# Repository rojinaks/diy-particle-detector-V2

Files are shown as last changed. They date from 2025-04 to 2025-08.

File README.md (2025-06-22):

# 🎛️ DIY Particle Detector v2.3

**Ein kompakter Teilchendetektor für Bildungs- und Outreach-Zwecke**, inspiriert vom DIY-particle-detector von Oliver Keller, weiterentwickelt am Physikalischen Institut der Universität Bonn.

---

### Dieses Repository enthält die Hardware- und Softwarebasis für einen DIY-Teilchendetektors

## ✨ Features

- SMD-basiertes PCB-Design  
- Python-Oszilloskop zur Signalvisualisierung 
- Dokumentierte Tests und Messergebnisse (Raumladungszone, Signal/noise Analyse)

---

## 📦 Inhalt

- `/hardware` → KiCad-Designs und Schaltpläne  
- `/codes` → Python-Auslesetool mit GUI, weitere messungen (Dioden Messung (Raumladungszone), Opamp vergleiche, Signal/noise Analyse)
- `/archives` → Weitere KiCad-Designs für vorherige Versionen  
- `/spice` → LTspice simulationen für verschiedene opamps

---

## Python Oszilloskop

```bash
  git clone https://github.com/rojinaks/diy-particle-detector-V2.git
  cd diy-particle-detector-V2/codes/auslese
  python oscilloscope.py

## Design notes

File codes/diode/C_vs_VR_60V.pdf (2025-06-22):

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

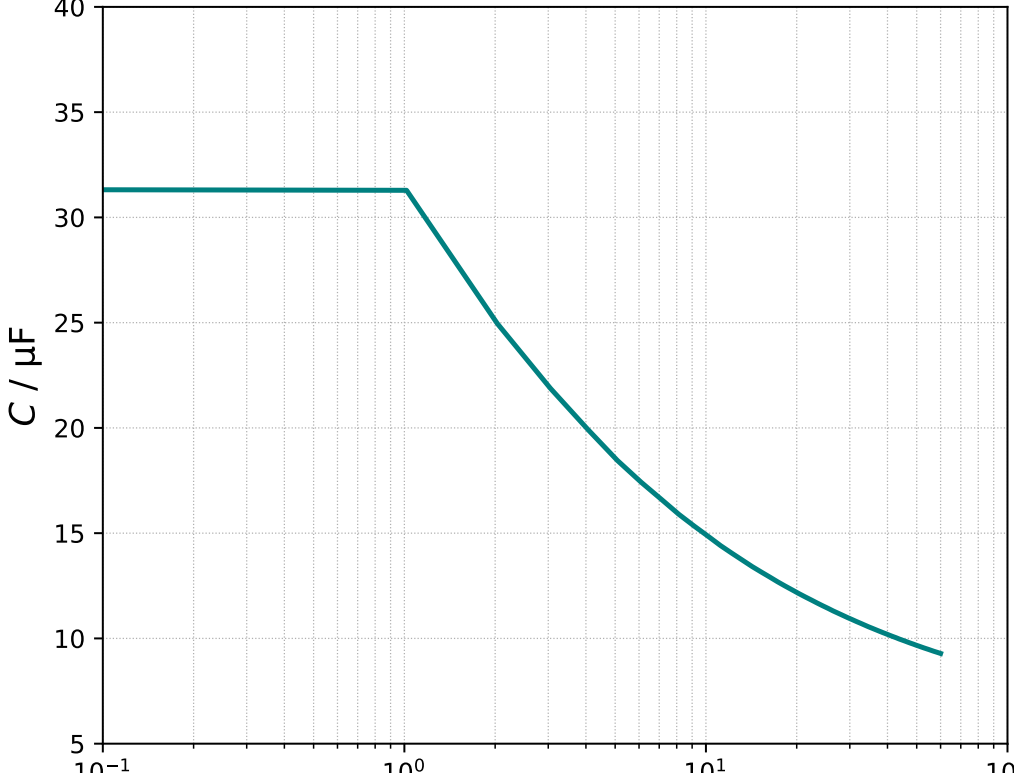
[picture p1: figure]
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

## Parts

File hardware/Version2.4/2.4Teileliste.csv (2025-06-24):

Reference | Qty | Value | DNP | Exclude from BOM | Exclude from Board | Footprint | Datasheet
C1,C2,C5 | 3 | 10p |  |  |  | Capacitor_SMD:C_0805_2012Metric | ~
C3,C4,C6,C7,C9 | 5 | 100n |  |  |  | Capacitor_SMD:C_0805_2012Metric | ~
C8 | 1 | 47mikro |  |  |  | footprints:PCAP_EEHZ_D_PAN | ~
D1,D2,D3,D4 | 4 | BPW34-SMD |  |  |  | footprints:LED_VBPW34S_VIS | https://dammedia.osram.info/media/resource/hires/osram-dam-5488319/BPW%2034%20S_EN.pdf
J1 | 1 | Conn_01x02 |  |  |  | footprints:CUI_SJ2-35813B-SMT-TR | ~
R1 | 1 | 4.7k |  |  |  | Resistor_SMD:R_0805_2012Metric | ~
R2 | 1 | 15k |  |  |  | Resistor_SMD:R_0805_2012Metric | ~
R3 | 1 | 4.7Mega |  |  |  | Resistor_SMD:R_0805_2012Metric | ~
R4 | 1 | 1k |  |  |  | Resistor_SMD:R_0805_2012Metric | ~
R5 | 1 | 100k |  |  |  | Resistor_SMD:R_0805_2012Metric | ~
R6,R7 | 2 | 10k |  |  |  | Resistor_SMD:R_0805_2012Metric | ~
R9 | 1 | 1.6k |  |  |  | Resistor_SMD:R_0805_2012Metric | ~
SW2 | 1 | SW_SPST |  |  |  | footprints:SWITCH_102AGRLC | ~
TP1 | 1 | - |  |  |  | Connector_PinHeader_2.54mm:PinHeader_1x01_P2.54mm_Vertical | ~
TP2 | 1 | + |  |  |  | Connector_PinHeader_2.54mm:PinHeader_1x01_P2.54mm_Vertical | ~
TP3,TP5 | 2 | TestPoint |  |  |  | Connector_PinHeader_2.54mm:PinHeader_1x01_P2.54mm_Vertical | ~
U1 | 1 | AD8092ARZ-REEL7 |  |  |  | footprints:R_8_ADI | AD8092ARZ-REEL7

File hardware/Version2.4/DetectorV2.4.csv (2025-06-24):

Id | Designator | Footprint | Quantity | Designation | Supplier and ref
1 | TP3,TP5 | PinHeader_1x01_P2.54mm_Vertical | 2 | TestPoint
2 | TP2 | PinHeader_1x01_P2.54mm_Vertical | 1 | +
3 | J1 | CUI_SJ2-35813B-SMT-TR | 1 | Conn_01x02
4 | R6,R7 | R_0805_2012Metric | 2 | 10k
5 | C1,C5,C2 | C_0805_2012Metric | 3 | 10p
6 | C9 | PCAP_EEHZ_D_PAN | 1 | 47mikro
7 | SW2 | SWITCH_102AGRLC | 1 | SW_SPST
8 | D3,D4,D1,D2 | LED_VBPW34S_VIS | 4 | BPW34-SMD
9 | C8,C3,C7,C4,C6 | C_0805_2012Metric | 5 | 100n
10 | TP1 | PinHeader_1x01_P2.54mm_Vertical | 1 | -
11 | R5 | R_0805_2012Metric | 1 | 100k
12 | U1 | R_8_ADI | 1 | AD8092ARZ-REEL7
13 | R8 | R_0805_2012Metric | 1 | 2.2k
14 | R1 | R_0805_2012Metric | 1 | 4.7k
15 | R3 | R_0805_2012Metric | 1 | 15Mega
16 | R2 | R_0805_2012Metric | 1 | 15k
17 | R4 | R_0805_2012Metric | 1 | 1k

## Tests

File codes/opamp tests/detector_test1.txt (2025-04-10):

time	V(output)
0.000000000000000e+00	4.457908e-14
4.999999980020986e-12	1.077057e-11
9.999999960041972e-12	1.287759e-11
7.999999968033578e-11	-4.102484e-11
3.199999987213431e-10	5.803861e-12
5.048191999967347e-05	-1.297262e-07
1.016819199996747e-04	-1.232862e-07
1.528819199996759e-04	-7.572640e-08
2.040819199996772e-04	-5.882045e-08
2.552819199996724e-04	-3.688593e-08
3.064819199996459e-04	-3.444984e-08
3.576819199996194e-04	-6.742303e-08
4.088819199995929e-04	-3.954036e-08
4.600819199995664e-04	-2.296448e-08
4.999997000000000e-04	-1.382142e-08
5.000000000000000e-04	-1.382315e-08
5.000000300000000e-04	-3.184307e-08
5.000000900000000e-04	-6.434022e-08
5.000001800000001e-04	-9.239285e-08
5.000003000000000e-04	-1.027593e-07
5.000003120000000e-04	-9.669981e-08
5.000003360000000e-04	-8.123373e-08
5.000003840000000e-04	-5.311550e-08
5.000004799999999e-04	-2.460597e-08
5.000006719999998e-04	-8.022090e-09
5.000018239999994e-04	5.711786e-08
5.000033599999988e-04	-1.537475e-07
5.000064319999976e-04	-3.442640e-06
5.000125759999953e-04	-2.187164e-05
5.000233673569872e-04	-7.606066e-05
5.000449500709712e-04	-2.053976e-04
5.001881154989391e-04	-1.040404e-03
5.003381154989392e-04	-1.818958e-03
5.004881154989393e-04	-2.507623e-03
5.006381154989394e-04	-3.099794e-03
5.007881154989395e-04	-3.638366e-03
5.009381154989395e-04	-4.123341e-03
5.010881154989396e-04	-4.554718e-03
5.012381154989397e-04	-4.932497e-03
5.013881154989398e-04	-5.256678e-03
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

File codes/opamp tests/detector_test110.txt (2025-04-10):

time	V(output)
0.000000000000000e+00	4.457908e-14
4.999997000000000e-04	-1.149799e-08
5.000000000000000e-04	-1.150331e-08
5.000000300000000e-04	-2.974804e-08
5.000000900000000e-04	-6.287148e-08
5.000001800000001e-04	-9.184528e-08
5.000003000000000e-04	-1.030562e-07
5.000003120000000e-04	-9.693772e-08
5.000003360000000e-04	-8.130880e-08
5.000003840000000e-04	-5.269109e-08
5.000004799999999e-04	-2.327454e-08
5.000006719999998e-04	-5.955013e-09
5.000018239999994e-04	6.010367e-08
5.000033599999988e-04	-1.476795e-07
5.000064319999976e-04	-3.427491e-06
5.000125759999953e-04	-2.184159e-05
5.000233665898433e-04	-7.601692e-05
5.000449477695392e-04	-2.053274e-04
5.001498858748780e-04	-8.201343e-04
5.002734373667720e-04	-1.465756e-03
5.005205403505599e-04	-2.548371e-03
5.010147463181359e-04	-4.102728e-03
5.019913088181359e-04	-5.934027e-03
5.029678713181359e-04	-6.801216e-03
5.039444338181359e-04	-7.063652e-03
5.049209963181359e-04	-7.059992e-03
5.068741213181359e-04	-6.772818e-03
5.116174248895645e-04	-5.852124e-03
5.163607284609930e-04	-5.008081e-03
5.211040320324216e-04	-4.240687e-03
5.258473356038502e-04	-3.549942e-03
5.305906391752788e-04	-2.935848e-03
5.353339427467073e-04	-2.398404e-03
5.400772463181359e-04	-1.937609e-03
5.446810409609930e-04	-1.538960e-03
5.492848356038503e-04	-1.176703e-03
5.538886302467074e-04	-8.508357e-04
5.584924248895646e-04	-5.613596e-04
5.630962195324217e-04	-3.082743e-04
5.677000141752789e-04	-9.157981e-05
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

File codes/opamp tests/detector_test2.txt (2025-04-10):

time	V(output)
0.000000000000000e+00	9.900045e-16
8.176825127106248e-07	-2.700443e-06
1.635365025421250e-06	-5.966769e-06
2.453047538131874e-06	-9.798978e-06
3.270730050842499e-06	-1.419707e-05
4.088412563553124e-06	-1.916104e-05
4.906095076263748e-06	-2.469090e-05
5.723777588974371e-06	-3.078664e-05
9.351009731831518e-06	-4.238709e-05
1.297824187468867e-05	-5.249124e-05
1.660547401754581e-05	-6.109908e-05
2.023270616040296e-05	-6.821061e-05
2.385993830326011e-05	-7.382583e-05
2.748717044611726e-05	-7.794475e-05
3.111440258897439e-05	-8.056736e-05
4.143806330326012e-05	-8.432712e-05
5.176172401754585e-05	-8.591930e-05
6.208538473183157e-05	-8.534389e-05
7.240904544611731e-05	-8.260089e-05
8.273270616040303e-05	-7.769031e-05
9.305636687468875e-05	-7.061214e-05
1.033800275889745e-04	-6.136639e-05
1.255268095773091e-04	-4.460414e-05
1.476735915656437e-04	-2.966823e-05
1.698203735539783e-04	-1.655864e-05
1.919671555423129e-04	-5.275388e-06
2.141139375306476e-04	4.181536e-06
2.362607195189822e-04	1.181213e-05
2.584075015073167e-04	1.761639e-05
2.629010563200887e-04	4.727535e-05
2.638229841095085e-04	4.463470e-05
2.647449118989284e-04	4.239051e-05
2.656668396883483e-04	4.054276e-05
2.665887674777682e-04	3.909146e-05
2.675106952671881e-04	3.803660e-05
2.684326230566079e-04	3.737820e-05
2.693545508460278e-04	3.711625e-05
2.740978544174563e-04	3.581382e-05
2.788411579888849e-04	3.439125e-05
2.835844615603135e-04	3.284855e-05
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

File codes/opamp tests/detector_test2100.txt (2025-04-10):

time	V(output)
0.000000000000000e+00	4.500020e-14
1.661160391134096e-05	-4.121589e-05
3.322320782268191e-05	-7.298883e-05
4.983481173402286e-05	-9.531881e-05
6.644641564536382e-05	-1.082058e-04
8.305801955670478e-05	-1.116499e-04
9.966962346804573e-05	-1.056510e-04
1.162812273793867e-04	-9.020913e-05
1.710981948966172e-04	-6.331407e-05
2.259151624138477e-04	-4.118642e-05
2.807321299310782e-04	-2.382618e-05
3.355490974483086e-04	-1.123336e-05
3.903660649655391e-04	-3.407946e-06
4.451830324827697e-04	-3.499476e-07
5.000000000000000e-04	-2.059362e-06
5.000000300000000e-04	-2.062032e-06
5.000000900000000e-04	-2.070502e-06
5.000001800000001e-04	-2.087911e-06
5.000003000000000e-04	-2.113405e-06
5.000003120000000e-04	-2.114961e-06
5.000003360000000e-04	-2.116687e-06
5.000004799999999e-04	-2.097844e-06
5.000006719999998e-04	-2.058885e-06
5.000010559999997e-04	-2.029344e-06
5.000018239999994e-04	-2.039168e-06
5.000031574759732e-04	-2.026207e-06
5.000072979111673e-04	-2.805569e-06
5.000116793956119e-04	-6.327371e-06
5.000178842841656e-04	-1.724781e-05
5.000273975666252e-04	-4.527592e-05
5.000391748948888e-04	-9.291667e-05
5.000525291308653e-04	-1.580664e-04
5.000719727481850e-04	-2.623872e-04
5.001477850951595e-04	-6.789644e-04
5.002332670349800e-04	-1.122735e-03
5.003730729582297e-04	-1.787976e-03
5.005635627429600e-04	-2.584830e-03
5.008303668230145e-04	-3.517586e-03
5.011796253414716e-04	-4.474500e-03
5.016543045588546e-04	-5.406892e-03
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

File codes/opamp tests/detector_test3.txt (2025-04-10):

time	V(output)
0.000000000000000e+00	9.917662e-16
1.785714274861660e-10	-1.752318e-07
3.571428549723319e-10	-3.727277e-07
5.357142824584979e-10	-5.924878e-07
7.142857099446638e-10	-8.345120e-07
8.928571374308298e-10	-1.098800e-06
1.071428564916996e-09	-1.385353e-06
1.249999992403161e-09	-1.694169e-06
2.499999984806323e-09	-2.570045e-06
4.999999969612645e-09	-2.384566e-06
3.999999975690116e-08	1.674039e-06
7.146281428550594e-05	8.634554e-07
1.428856285712550e-04	2.536647e-07
2.143084428570040e-04	-1.553336e-07
2.857312571427531e-04	-3.635395e-07
3.571540714285021e-04	-3.709529e-07
4.285768857142511e-04	-1.775738e-07
4.999997000000000e-04	2.165976e-07
5.000000000000000e-04	2.157098e-07
5.000000300000000e-04	2.020554e-07
5.000000900000000e-04	1.557575e-07
5.000001800000001e-04	4.638466e-08
5.000003000000000e-04	-1.367757e-07
5.000003120000000e-04	-1.553009e-07
5.000003360000000e-04	-1.875273e-07
5.000003840000000e-04	-2.322087e-07
5.000004799999999e-04	-2.657006e-07
5.000006719999998e-04	-2.221443e-07
5.000010559999997e-04	-2.195983e-08
5.000018239999994e-04	3.275698e-07
5.000033599999988e-04	6.399246e-07
5.000064319999976e-04	-5.064086e-08
5.000125759999953e-04	-6.665186e-06
5.000248639999906e-04	-3.646352e-05
5.000494399999812e-04	-1.303520e-04
5.000922667152987e-04	-3.303421e-04
5.001341581592522e-04	-5.358063e-04
5.001849418220838e-04	-7.789372e-04
5.002865091477471e-04	-1.233778e-03
5.004896437990737e-04	-2.036656e-03
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

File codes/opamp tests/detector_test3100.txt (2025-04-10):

time	V(output)
0.000000000000000e+00	4.508028e-14
1.785714274861660e-10	-1.776339e-07
3.571428549723319e-10	-3.791228e-07
5.357142824584979e-10	-6.044669e-07
7.142857099446638e-10	-8.536660e-07
8.928571374308298e-10	-1.126720e-06
1.071428564916996e-09	-1.423629e-06
1.249999992403161e-09	-1.744394e-06
2.499999984806323e-09	-2.659528e-06
4.999999969612645e-09	-2.463301e-06
2.714285697789723e-08	-2.949711e-07
4.928571398618181e-08	1.270683e-06
7.142857099446639e-08	2.233660e-06
9.357142800275097e-08	2.593962e-06
1.157142850110355e-07	2.351588e-06
1.378571420193201e-07	1.506538e-06
1.599999990276046e-07	5.881238e-08
4.999997000000000e-04	3.424397e-08
5.000000000000000e-04	3.339565e-08
5.000000300000000e-04	1.967624e-08
5.000000900000000e-04	-2.693382e-08
5.000001800000001e-04	-1.374386e-07
5.000003000000000e-04	-3.230272e-07
5.000003120000000e-04	-3.419420e-07
5.000003360000000e-04	-3.749843e-07
5.000003840000000e-04	-4.213241e-07
5.000004799999999e-04	-4.577254e-07
5.000006719999998e-04	-4.174168e-07
5.000010559999997e-04	-2.161339e-07
5.000018239999994e-04	1.448294e-07
5.000033599999988e-04	4.729140e-07
5.000064319999976e-04	-2.384377e-07
5.000125759999953e-04	-7.039956e-06
5.000248639999906e-04	-3.749422e-05
5.000494399999812e-04	-1.335283e-04
5.000985919999624e-04	-3.666603e-04
5.001968959999249e-04	-8.386631e-04
5.003722311177947e-04	-1.598754e-03
5.007229013535343e-04	-2.828579e-03
5.014242418250135e-04	-4.585809e-03
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

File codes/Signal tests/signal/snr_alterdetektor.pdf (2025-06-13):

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

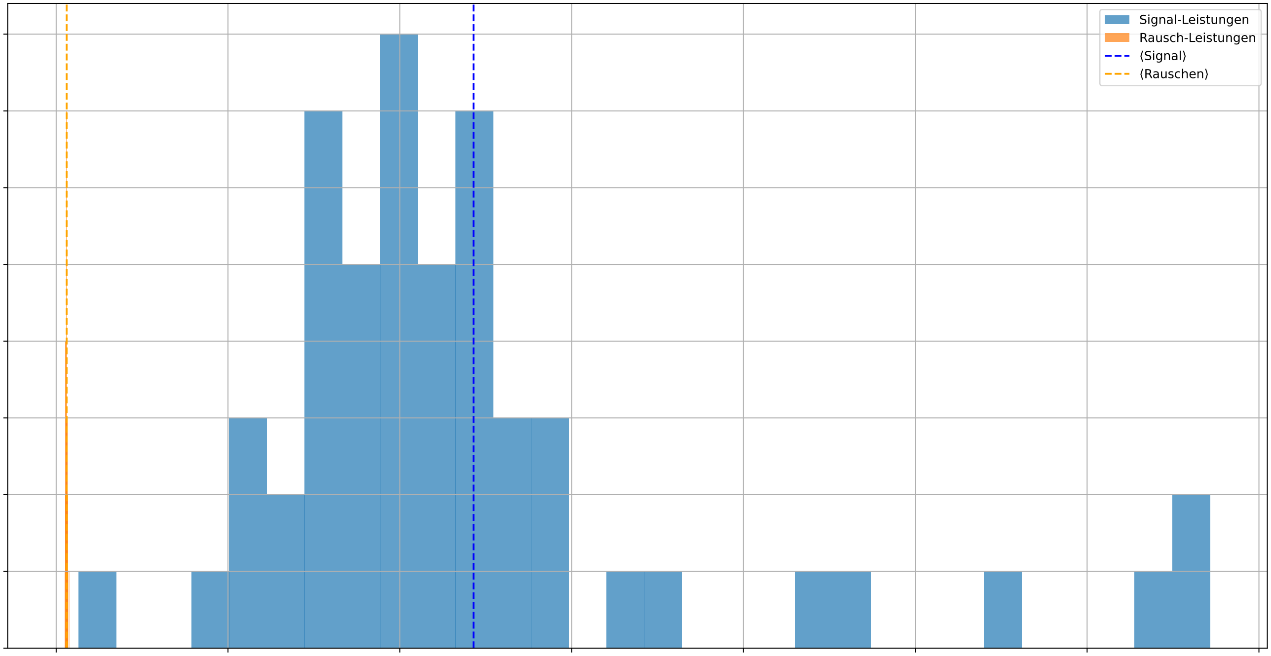
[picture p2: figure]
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

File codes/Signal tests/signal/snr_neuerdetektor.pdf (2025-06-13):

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

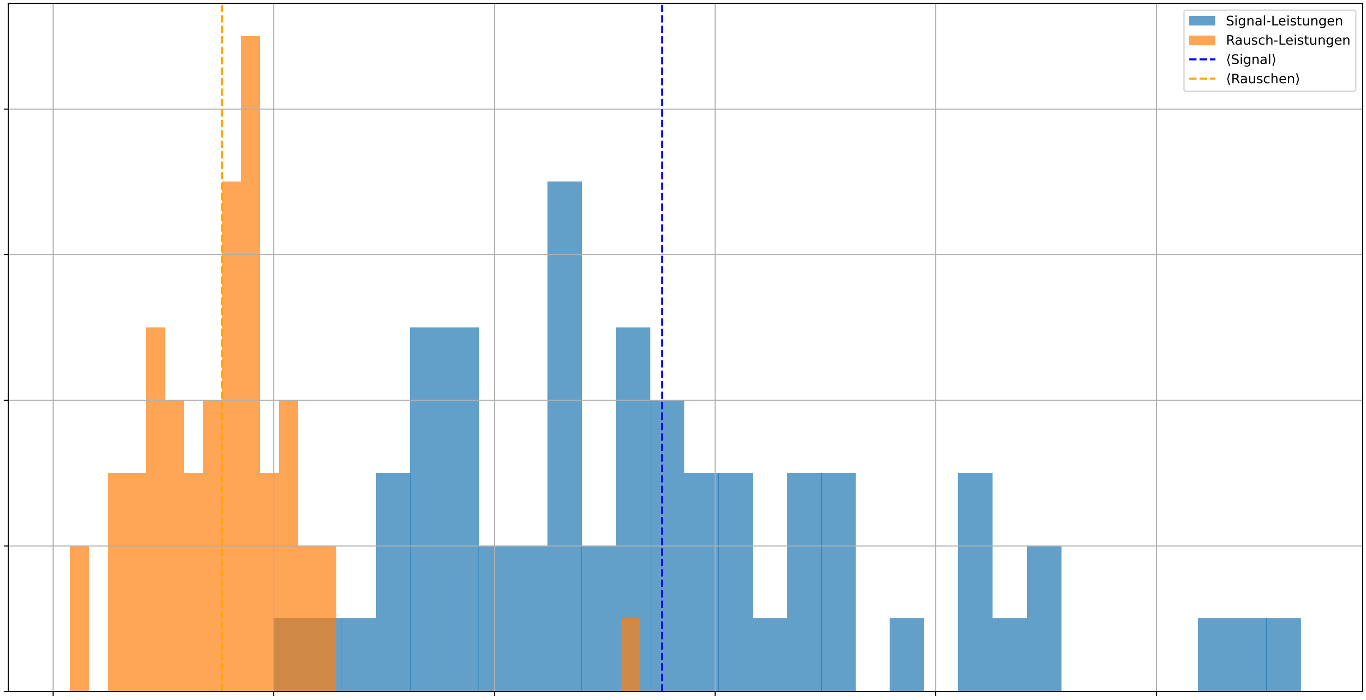
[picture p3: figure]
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

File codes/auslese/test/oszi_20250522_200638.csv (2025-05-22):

Zeit [s] | Spannung [mV]
0.0 | -7.4963317
2.269790288223468e-05 | -5.7974477
4.539580576446936e-05 | -4.0358577
6.809370864670405e-05 | 0.18808834
9.079161152893873e-05 | 6.9413195
0.0001134895144111734 | 9.741846
0.0001361874172934081 | 14.804322
0.00015888532017564277 | 19.080292
0.00018158322305787745 | 19.206087
0.00020428112594011213 | 20.819496
0.0002269790288223468 | 24.23957
0.0002496769317045815 | 20.858429
0.0002723748345868162 | 19.46584
0.00029507273746905084 | 24.058937
0.00031777064035128555 | 23.859095
0.0003404685432335202 | 23.698092
0.0003631664461157549 | 26.392279
0.0003858643489979896 | 28.499405
0.00040856225188022426 | 26.544106
0.00043126015476245897 | 30.094652
0.0004539580576446936 | 33.4248
0.0004766559605269283 | 33.244843
0.000499353863409163 | 38.714306
0.0005220517662913977 | 43.714653
0.0005447496691736324 | 42.830906
0.0005674475720558671 | 43.12498
0.0005901454749381017 | 49.081627
0.0006128433778203364 | 50.004757
0.0006355412807025711 | 51.450848
0.0006582391835848058 | 50.930145
0.0006809370864670404 | 52.732384
0.0007036349893492751 | 60.9915
0.0007263328922315098 | 62.335968
0.0007490307951137445 | 65.67565
0.0007717286979959792 | 73.397316
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

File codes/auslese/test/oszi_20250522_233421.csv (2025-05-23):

Zeit [s] | Spannung [mV]
0.0 | 37.223328
2.2681274381954655e-05 | 39.65413
4.536254876390931e-05 | 37.315243
6.804382314586397e-05 | 32.851875
9.072509752781862e-05 | 26.904228
0.00011340637190977327 | 19.945705
0.00013608764629172794 | 16.24759
0.00015876892067368258 | 16.059284
0.00018145019505563724 | 17.126307
0.0002041314694375919 | 21.47739
0.00022681274381954655 | 27.470026
0.0002494940182015012 | 34.61243
0.0002721752925834559 | 45.994343
0.0002948565669654105 | 60.976265
0.00031753784134736516 | 77.77131
0.00034021911572931985 | 98.77025
0.0003629003901112745 | 124.62876
0.0003855816644932291 | 148.63481
0.0004082629388751838 | 169.50392
0.00043094421325713846 | 189.0923
0.0004536254876390931 | 203.6952
0.0004763067620210478 | 211.5432
0.0004989880364030024 | 213.91193
0.0005216693107849571 | 211.76436
0.0005443505851669118 | 206.23781
0.0005670318595488664 | 198.0991
0.000589713133930821 | 187.89703
0.0006123944083127757 | 176.91444
0.0006350756826947303 | 164.16225
0.0006577569570766851 | 149.13805
0.0006804382314586397 | 132.90779
0.0007031195058405943 | 114.26668
0.000725800780222549 | 90.41162
0.0007484820546045036 | 62.171684
0.0007711633289864582 | 31.755209
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

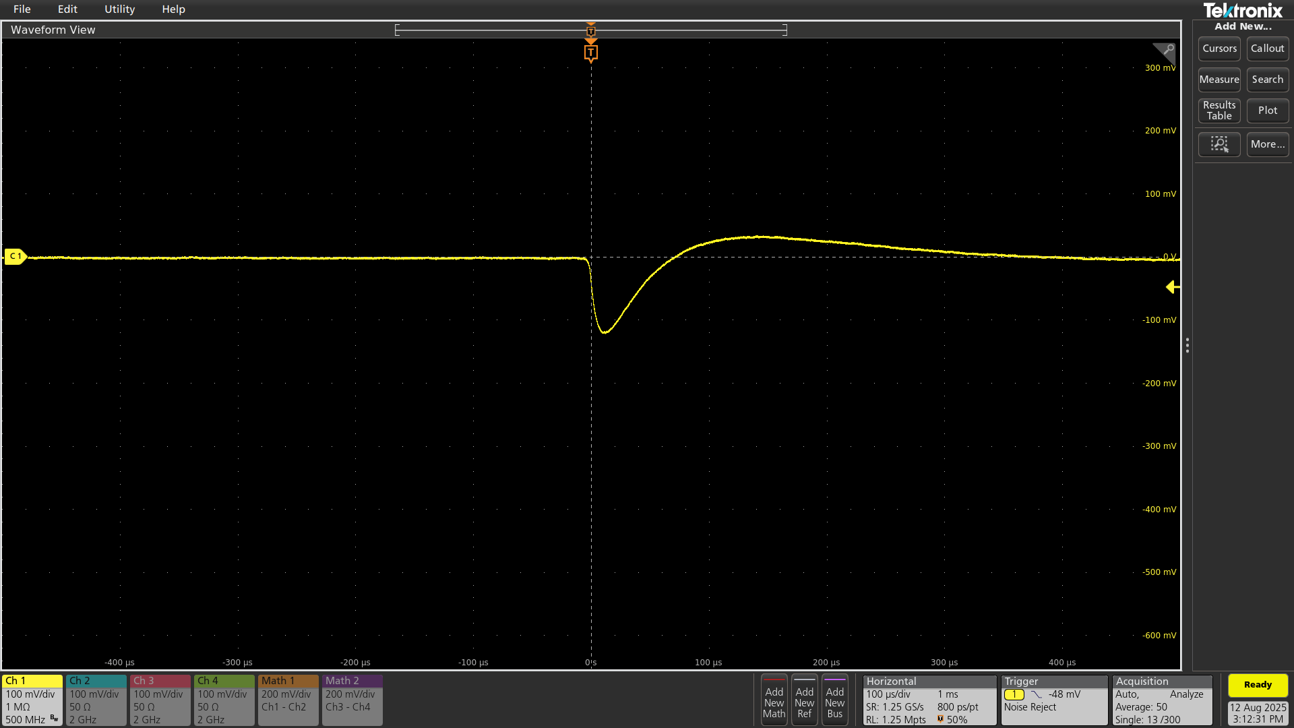
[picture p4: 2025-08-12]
codes/Signal tests/messungen2_4/Tek001_001.png

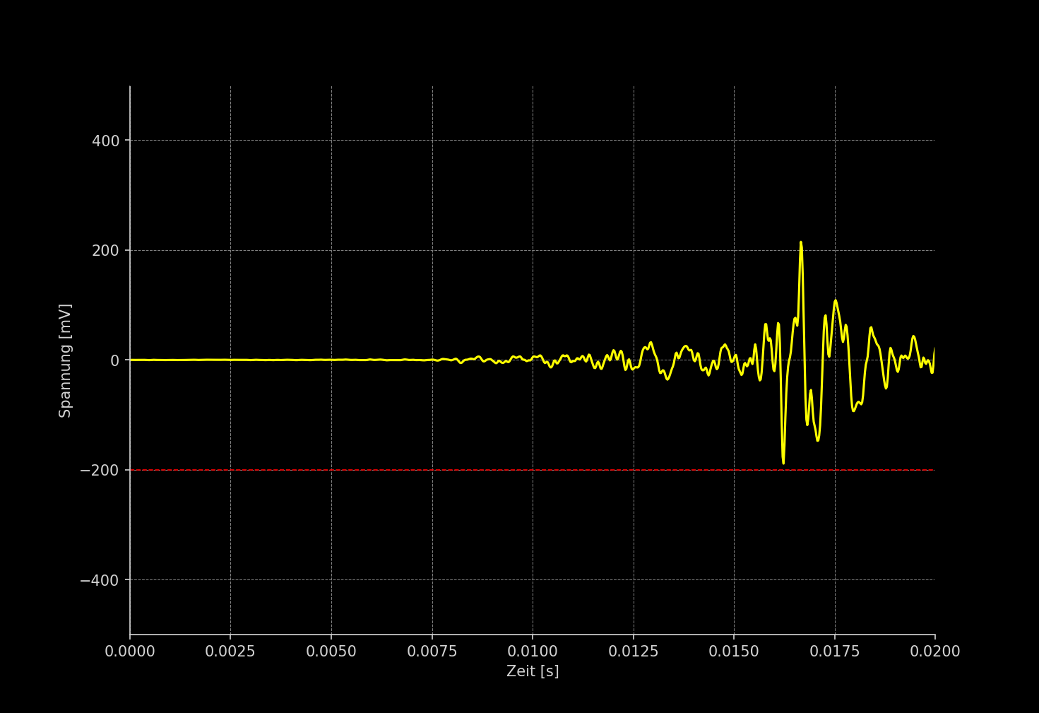
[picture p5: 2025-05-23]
codes/auslese/test/oszi_20250523_120948.png

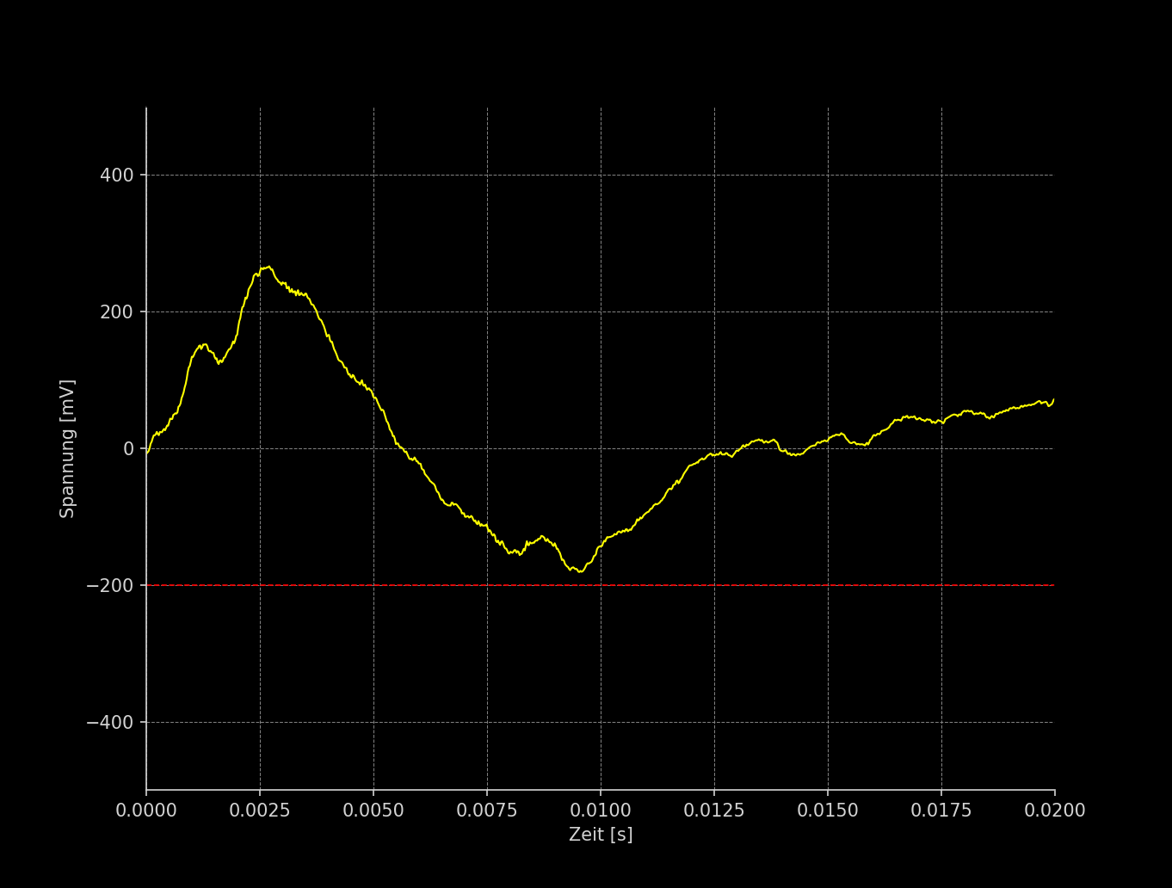
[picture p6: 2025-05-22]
codes/auslese/test/oszi_20250522_200635.png

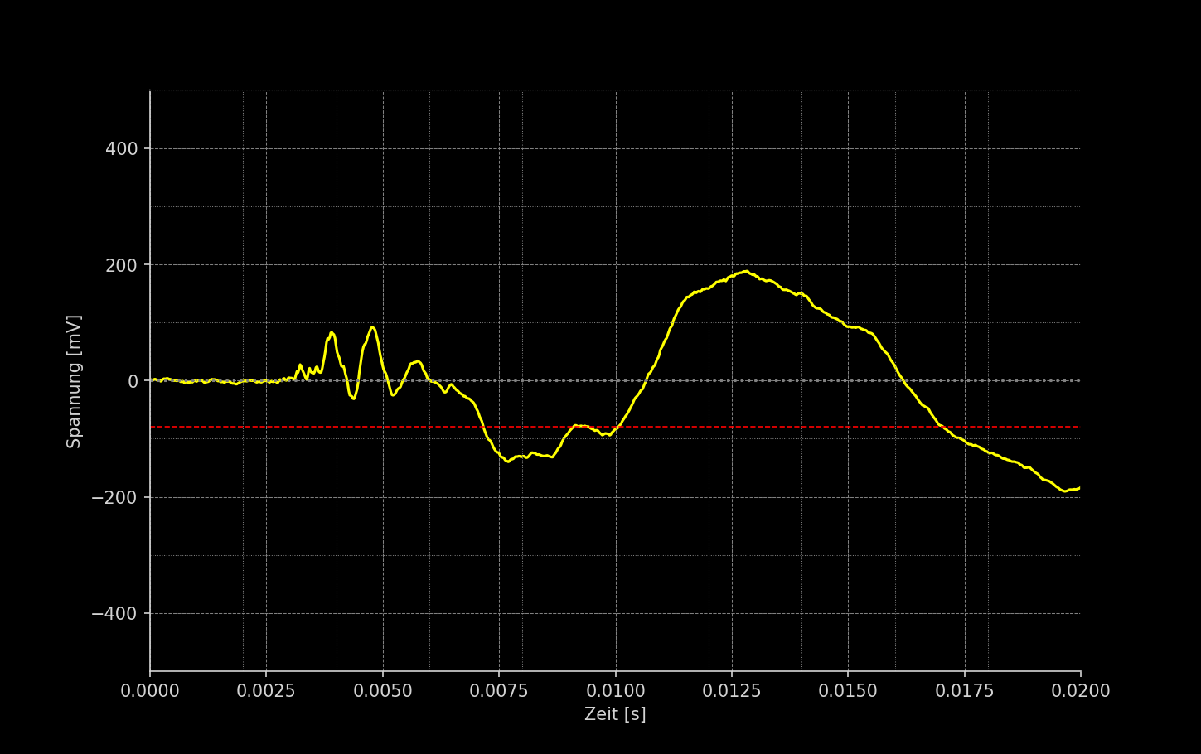
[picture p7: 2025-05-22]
codes/auslese/test/oszi_20250522_202935.png

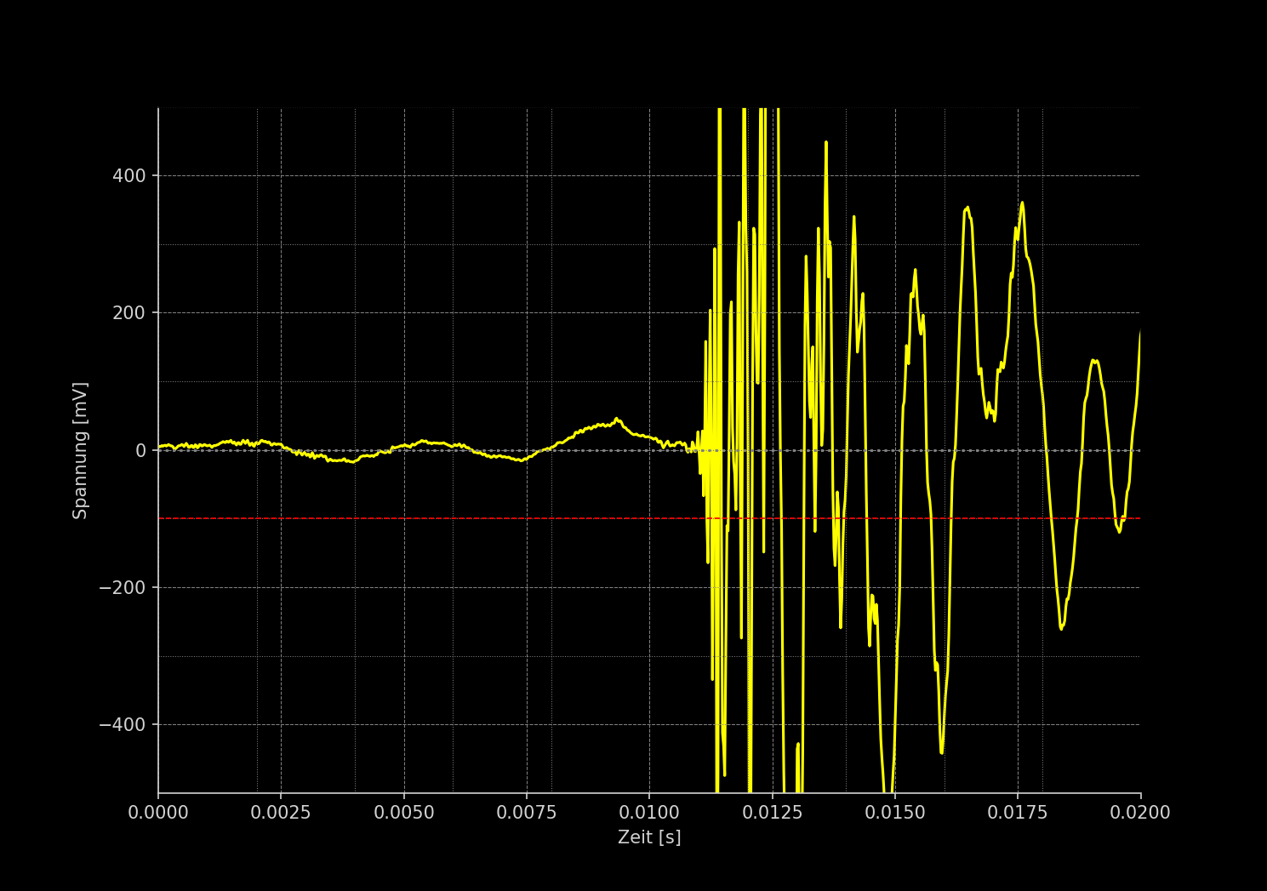
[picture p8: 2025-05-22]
codes/auslese/test/oszi_20250522_203145.png

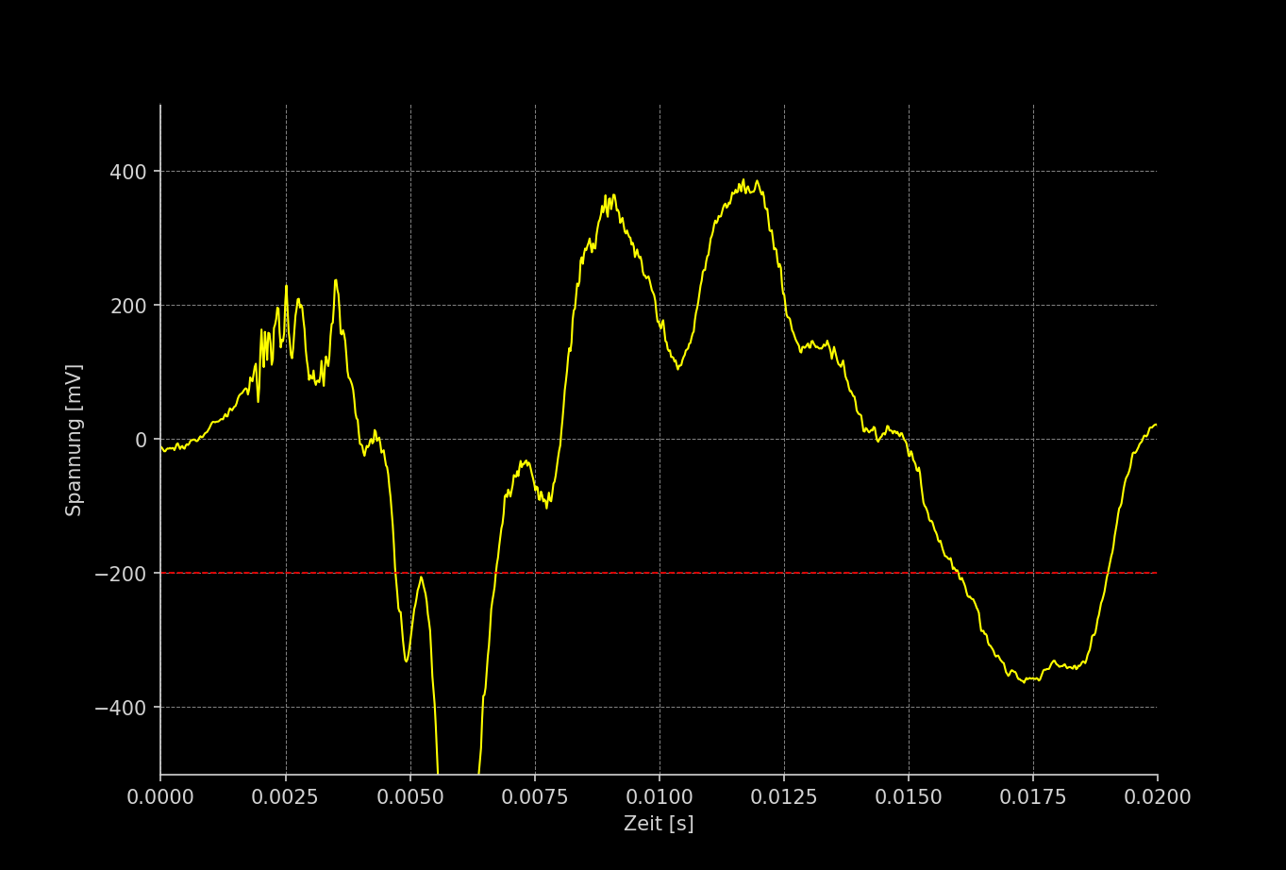
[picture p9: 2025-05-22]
codes/auslese/test/oszi_20250522_195904.png

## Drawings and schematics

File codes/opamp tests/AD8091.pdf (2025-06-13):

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

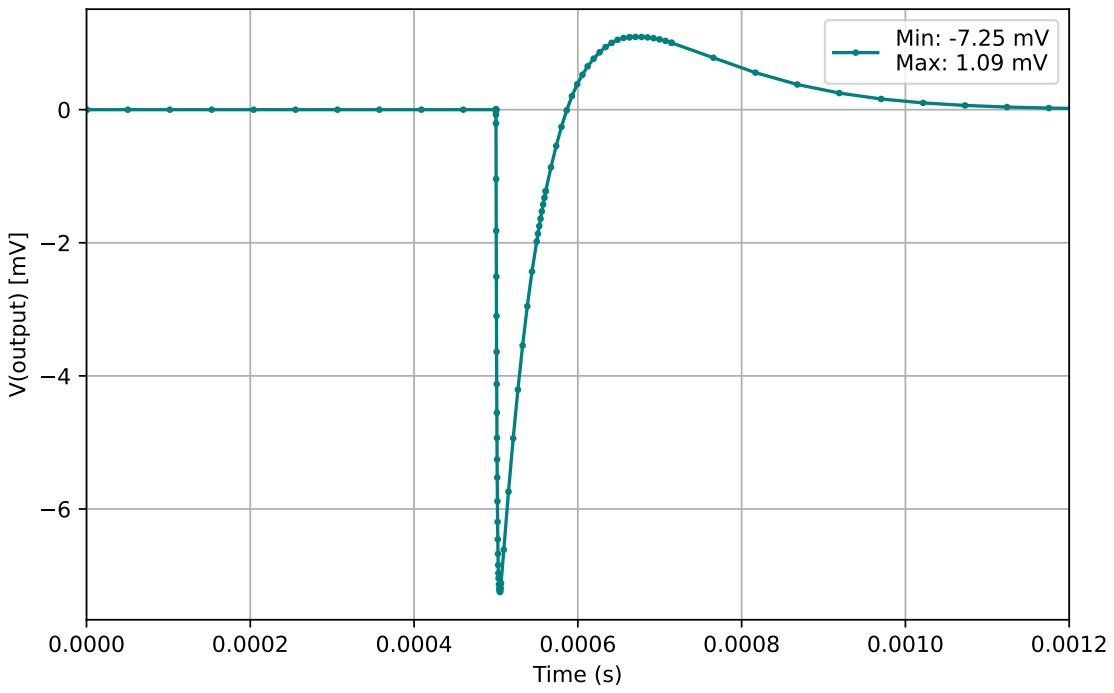
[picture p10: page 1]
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

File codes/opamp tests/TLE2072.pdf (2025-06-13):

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

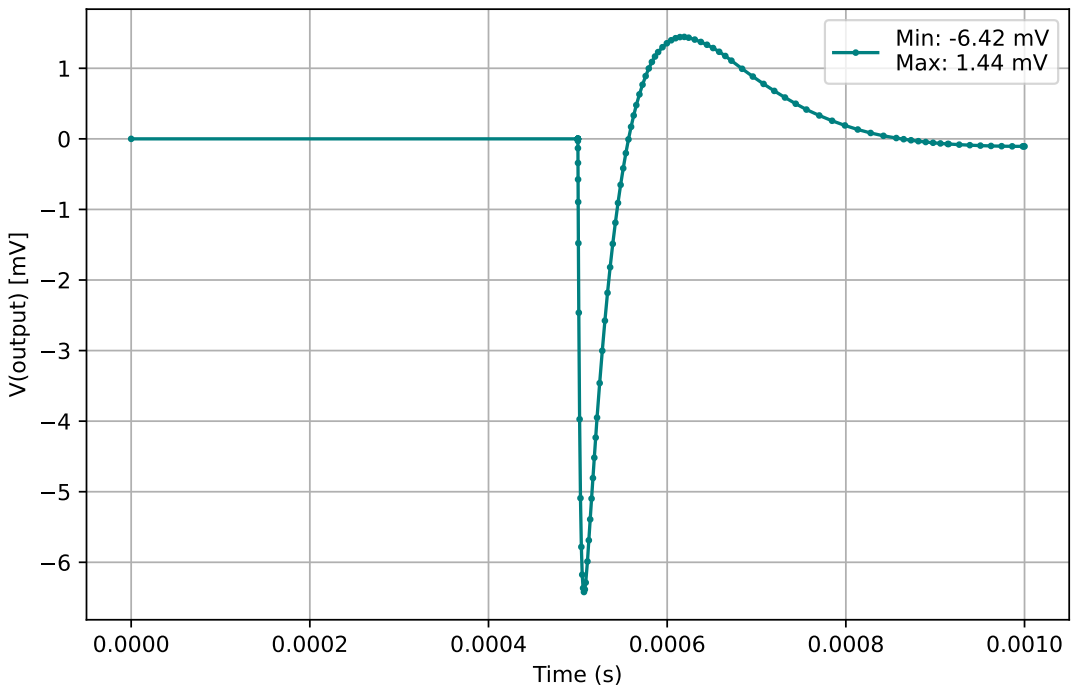
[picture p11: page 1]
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

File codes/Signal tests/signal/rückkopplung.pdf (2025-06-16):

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

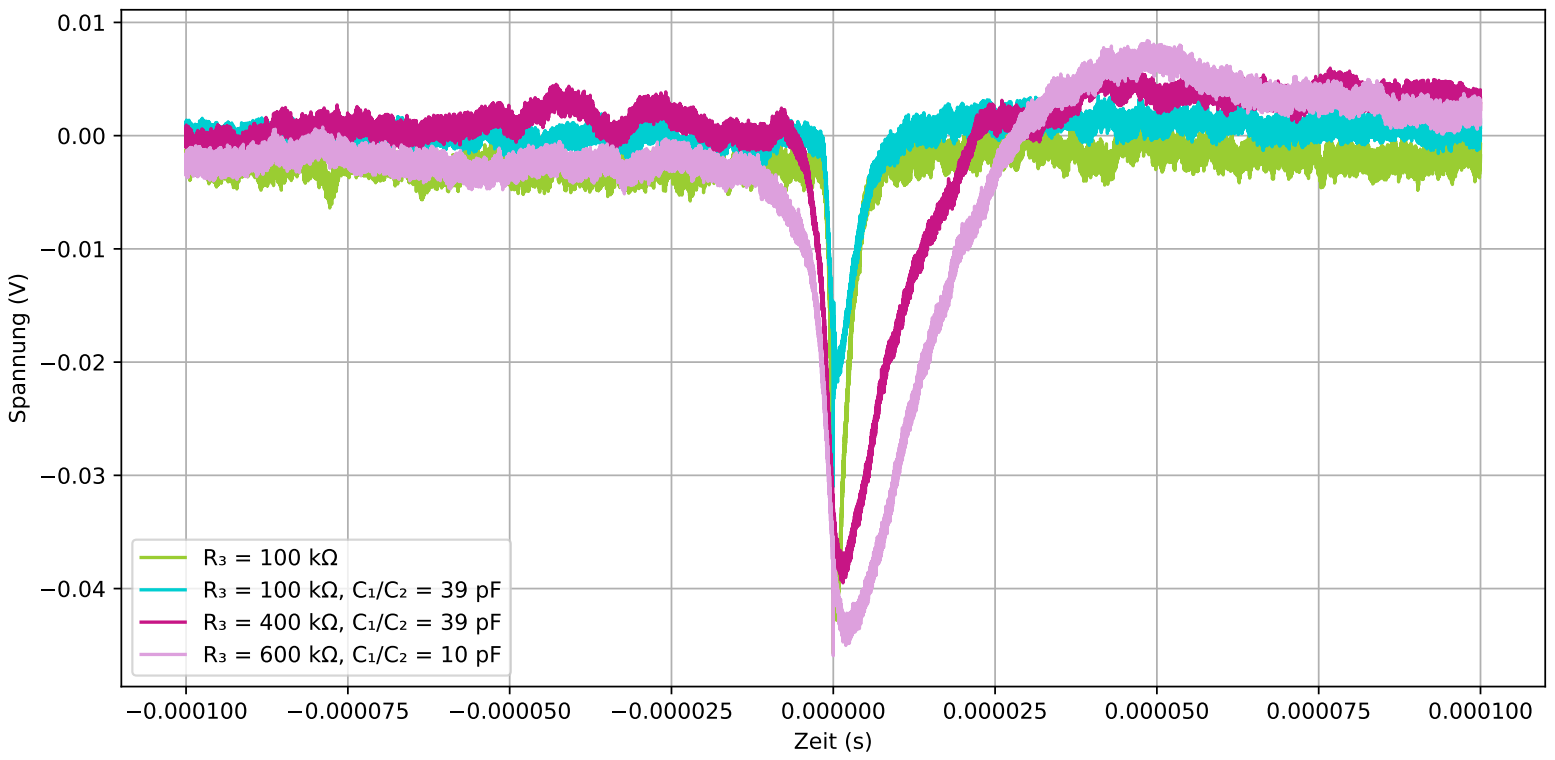
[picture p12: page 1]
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

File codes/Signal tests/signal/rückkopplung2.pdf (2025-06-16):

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

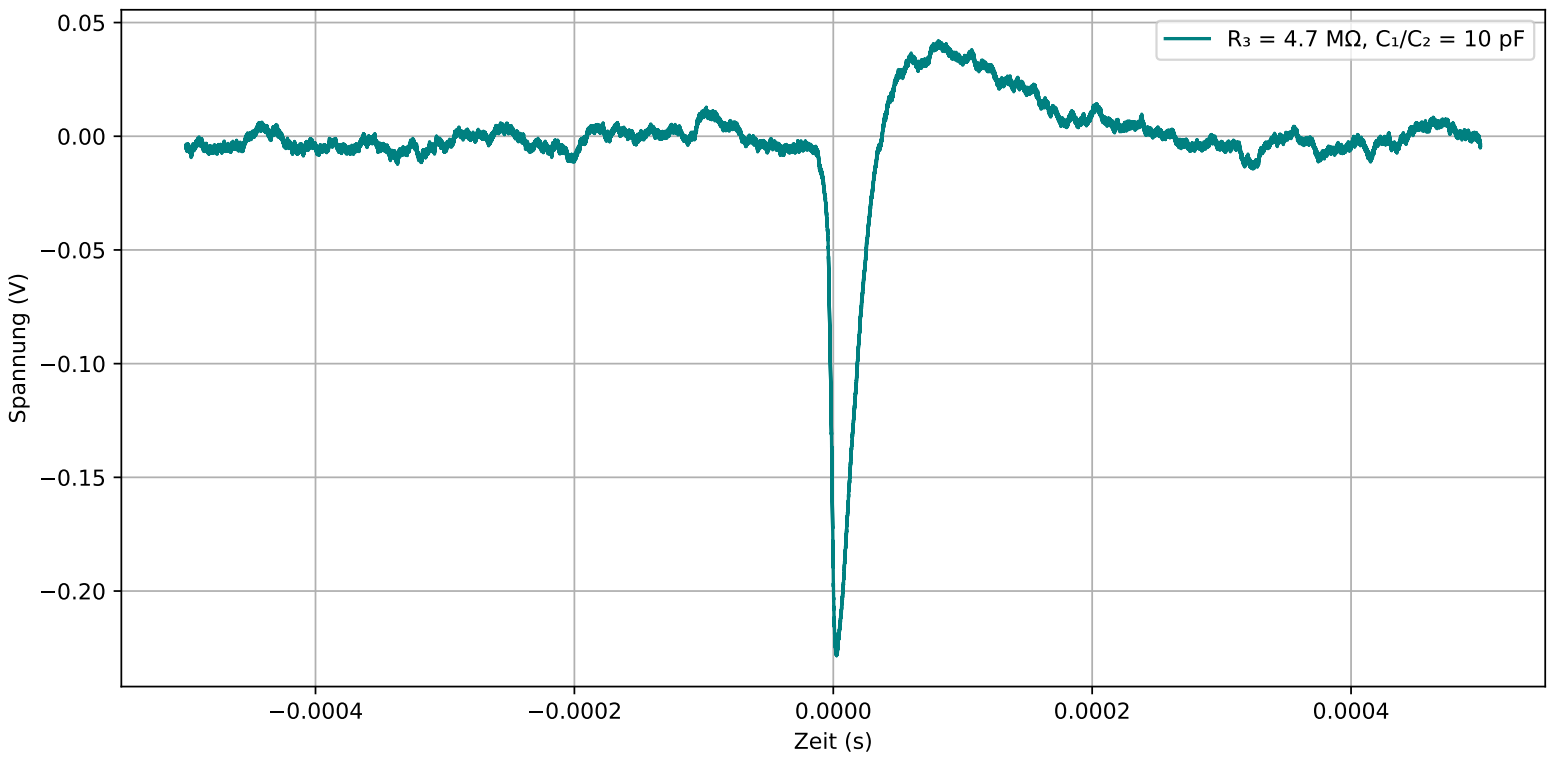
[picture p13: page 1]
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

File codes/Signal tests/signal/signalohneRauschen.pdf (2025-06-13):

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

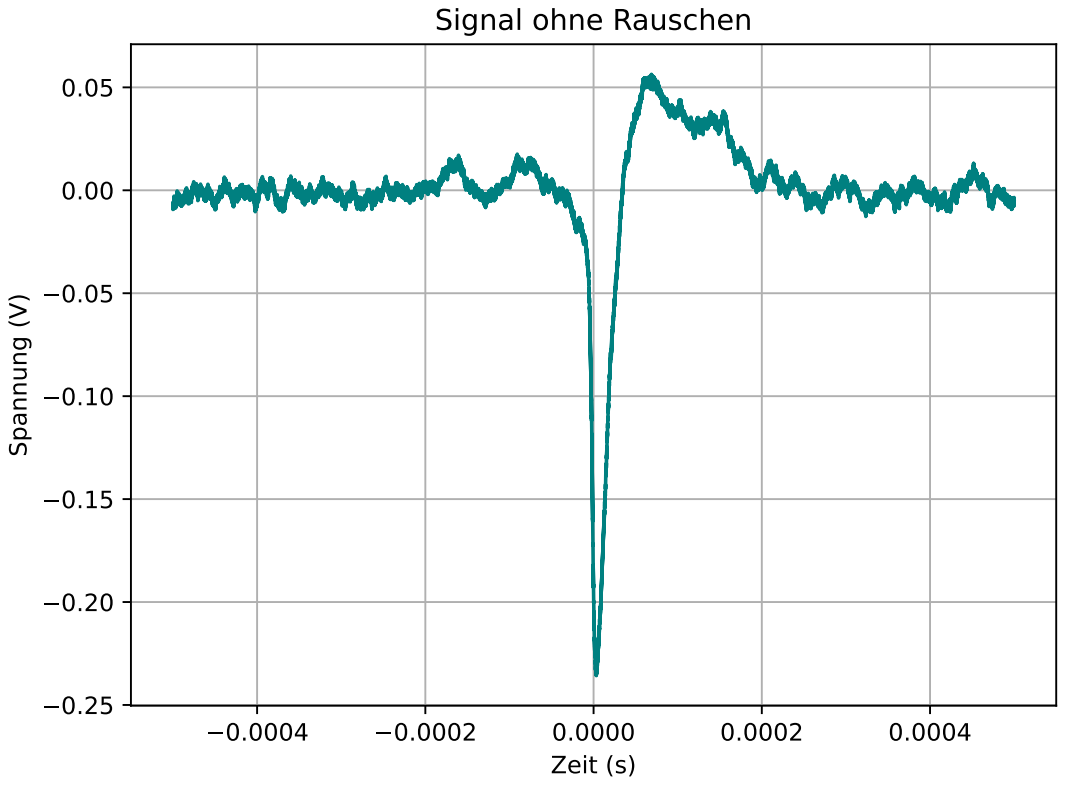
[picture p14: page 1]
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

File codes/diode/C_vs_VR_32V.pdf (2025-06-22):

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

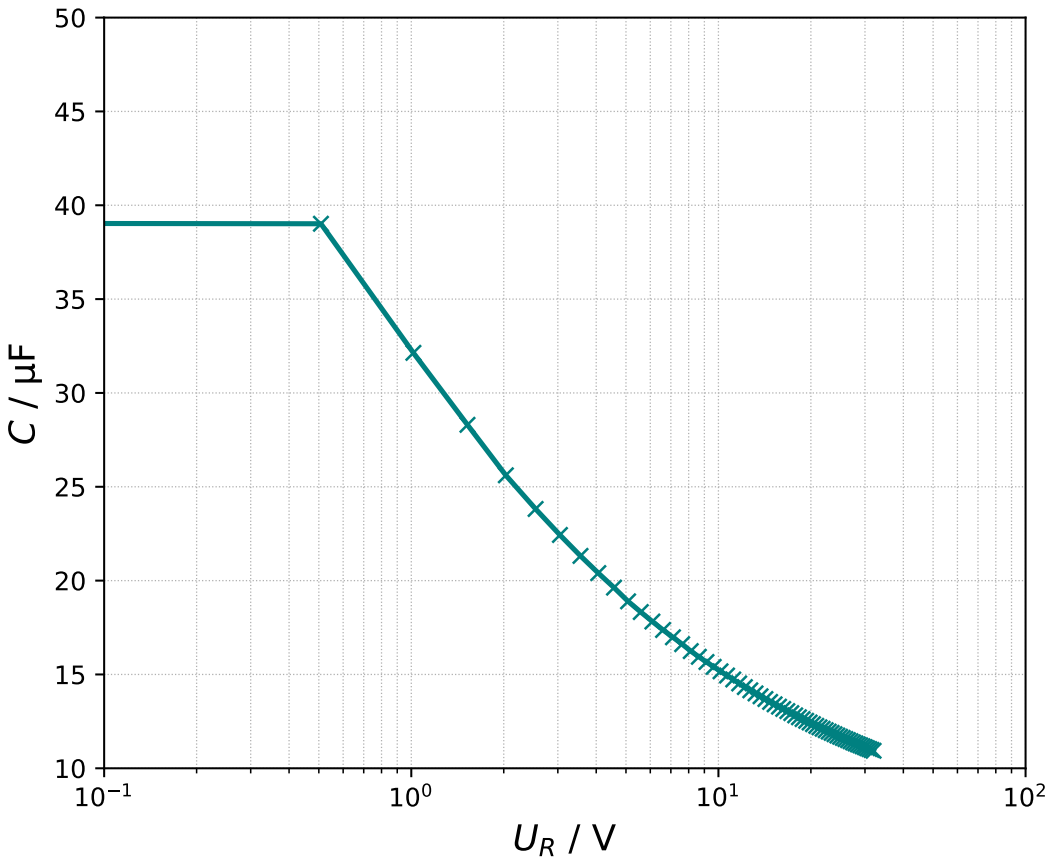
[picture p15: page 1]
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

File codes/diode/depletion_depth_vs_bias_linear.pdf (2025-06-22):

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

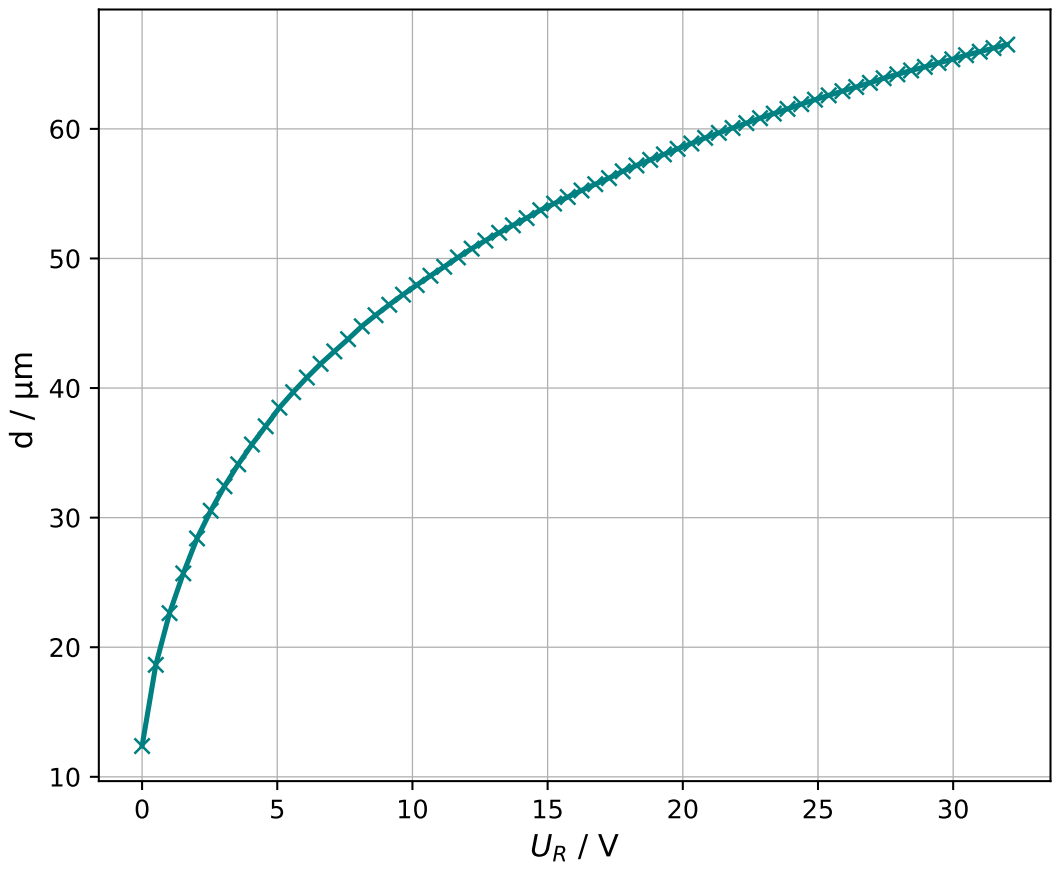
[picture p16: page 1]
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

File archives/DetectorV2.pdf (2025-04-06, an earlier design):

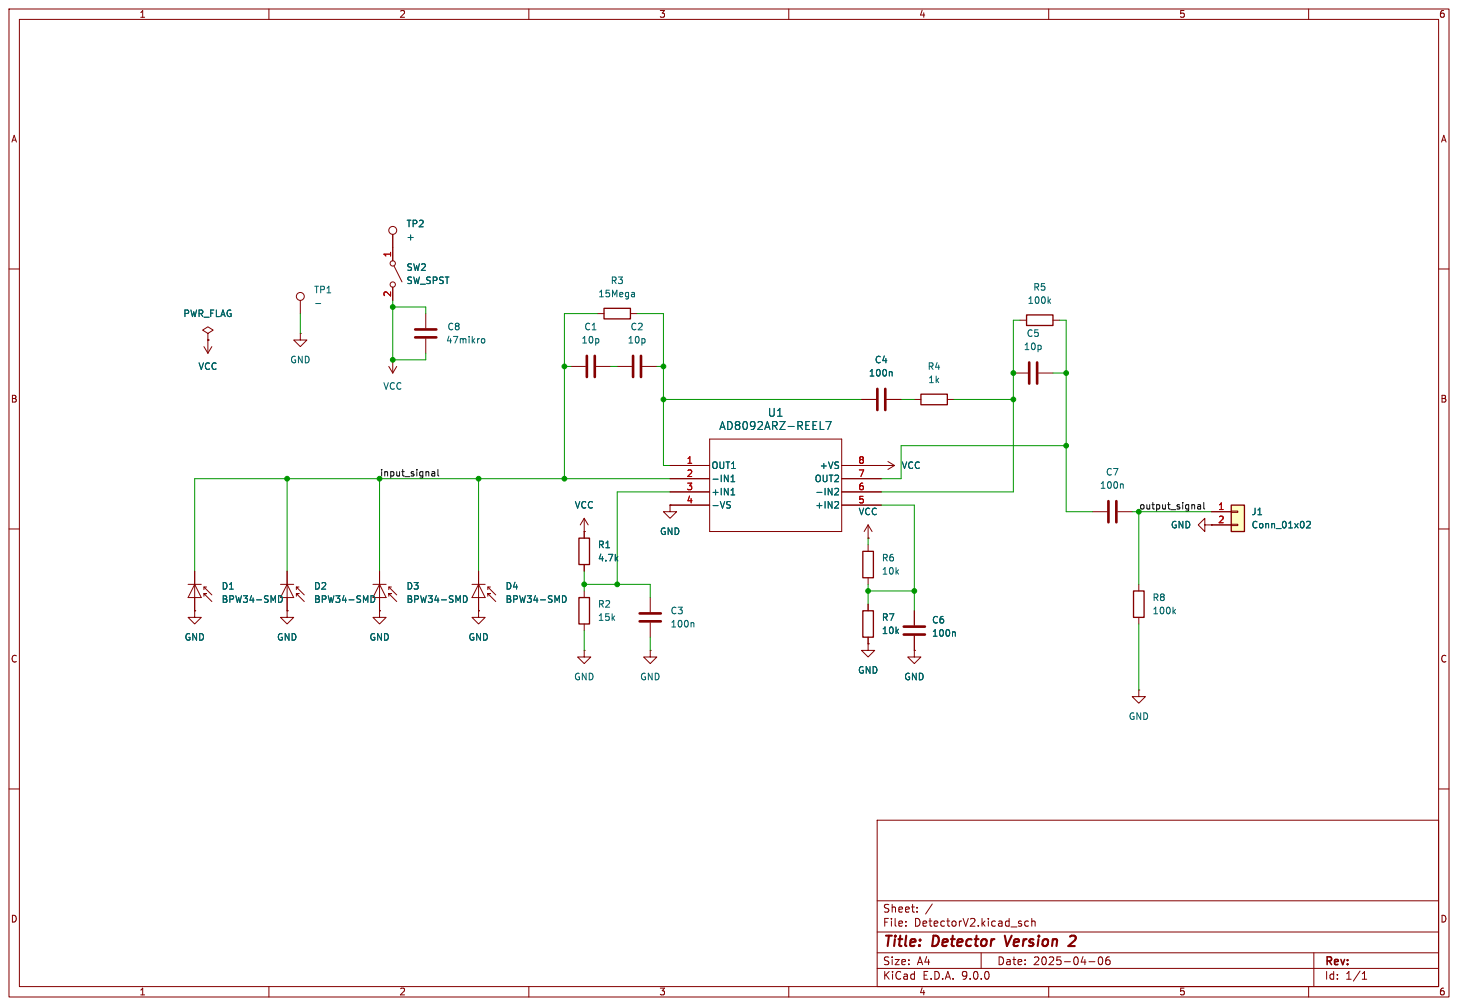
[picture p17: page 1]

Id: 1/1 Title: Detector Version 2

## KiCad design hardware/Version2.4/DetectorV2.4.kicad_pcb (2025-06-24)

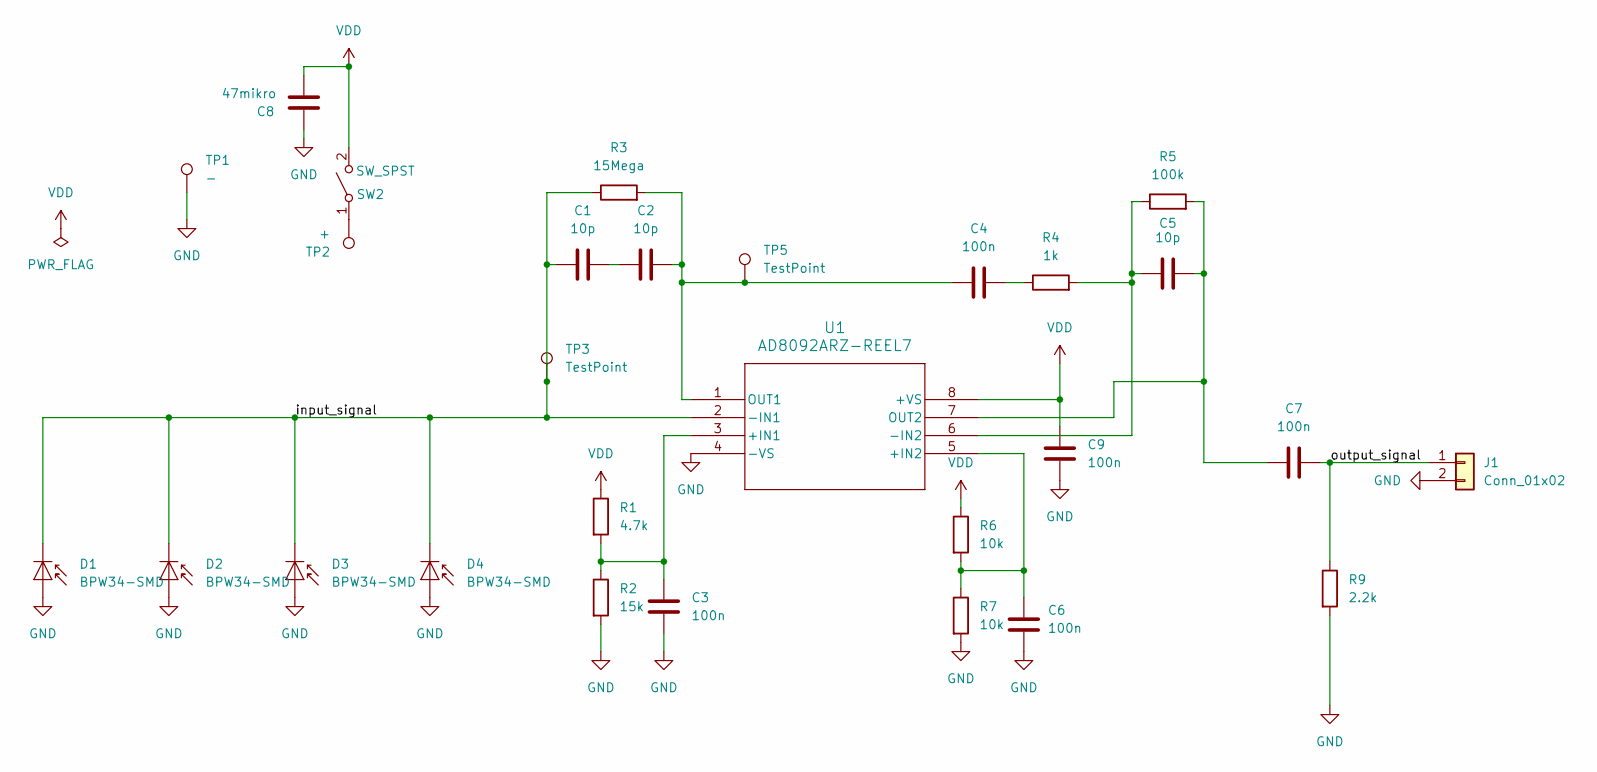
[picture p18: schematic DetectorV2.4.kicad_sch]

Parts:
C1, C2, C5: 10p; C_0805_2012Metric
C3, C4, C6, C7, C9: 100n; C_0805_2012Metric
C8: 47mikro; PCAP_EEHZ_D_PAN
D1, D2, D3, D4: BPW34-SMD; LED_VBPW34S_VIS
J1: Conn_01x02; CUI_SJ2-35813B-SMT-TR
R1: 4.7k; R_0805_2012Metric
R2: 15k; R_0805_2012Metric
R3: 15Mega; R_0805_2012Metric
R4: 1k; R_0805_2012Metric
R5: 100k; R_0805_2012Metric
R6, R7: 10k; R_0805_2012Metric
R9: 2.2k; R_0805_2012Metric
SW2: SW_SPST; SWITCH_102AGRLC
TP1: -; PinHeader_1x01_P2.54mm_Vertical
TP2: +; PinHeader_1x01_P2.54mm_Vertical
TP3, TP5: TestPoint; PinHeader_1x01_P2.54mm_Vertical
U1: AD8092ARZ-REEL7; R_8_ADI

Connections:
/input_signal: C1.1, D1.1 (K), D2.1 (K), D3.1 (K), D4.1 (K), R3.1, TP3.1, U1.2 (-IN1)
/output_signal: C7.2, J1.1, R9.1; also elsewhere on the board
GND: C3.2, C6.1, C8.2, C9.2, D1.2 (A), D2.2 (A), D3.2 (A), D4.2 (A), J1.2, R2.2, R7.2, R9.2, TP1.1, U1.4 (-VS); also elsewhere on the board
unnamed: C1.2, C2.1
unnamed: C4.2, R4.1
unnamed: SW2.1 (A), TP2.1
unnamed: C3.1, R1.2, R2.1, U1.3 (+IN1)
unnamed: C6.2, R6.2, R7.1, U1.5 (+IN2)
unnamed: C5.1, R4.2, R5.1, U1.6 (-IN2)
unnamed: C2.2, C4.1, R3.2, TP5.1, U1.1 (OUT1)
unnamed: C5.2, C7.1, R5.2, U1.7 (OUT2)
VDD: C8.1, C9.1, R1.1, R6.1, SW2.2 (B), U1.8 (+VS)

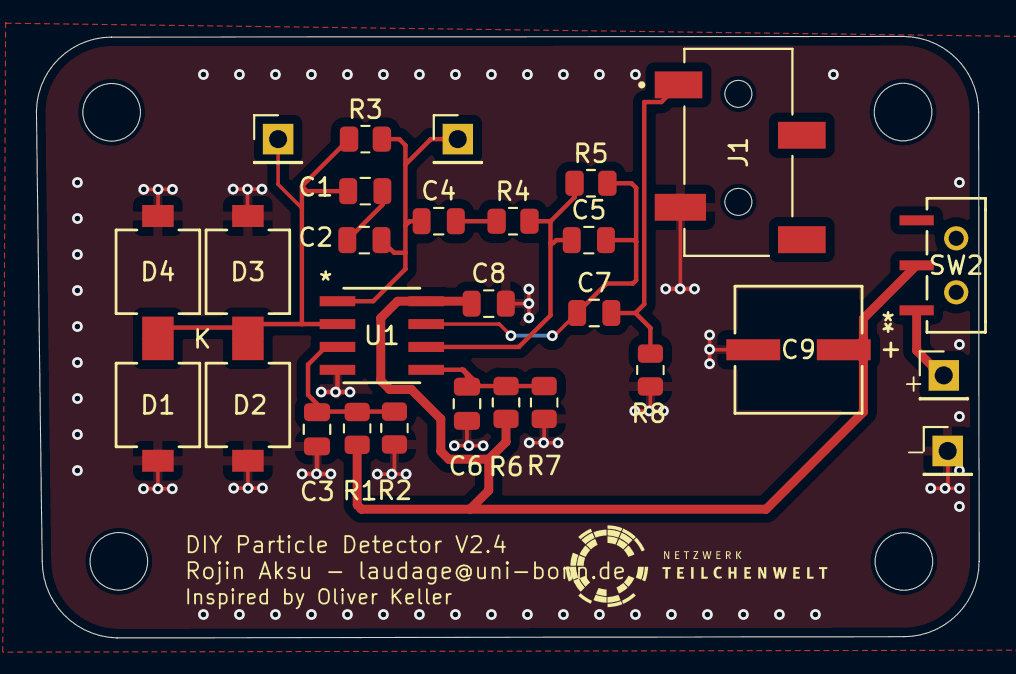
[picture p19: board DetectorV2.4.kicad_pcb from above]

Board: 2 copper layers, 52.4 x 33.4 mm, 28 parts (0 on the bottom side), 12 nets.

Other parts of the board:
R8: 2.2k; R_0805_2012Metric

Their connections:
/output_signal: R8.1; also elsewhere on the board
GND: R8.2; also elsewhere on the board

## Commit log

2025-04-03 Initial KiCad commit
    [DetectorV2.kicad_pcb, DetectorV2.kicad_sch]
2025-04-03 updated pdf without switch
2025-04-06 updated version - mit schalter + 47uF footprint
    [DetectorV2.kicad_pcb, DetectorV2.kicad_sch]
2025-04-06 updated mit allen teilen aber fehlerhaft
    [DetectorV2.kicad_pcb, DetectorV2.kicad_sch]
2025-04-06 änderung von paar werten aus simulation
    [DetectorV2.kicad_sch]
2025-04-10 version 2.2
    [DetectorV2.2.kicad_pcb]
2025-04-10 mit version 2.2
    [DetectorV2.2.kicad_pcb, DetectorV2.2.kicad_sch]
2025-04-10 Bill of Materials
    [DetectorV2.2.csv]
2025-04-11 version 2.3
    [DetectorV2.3.kicad_pcb, DetectorV2.3.kicad_sch]
2025-04-12 updated version 2.3
    [DetectorV2.3.kicad_pcb, DetectorV2.3.kicad_sch]
2025-04-12 Bill of materials 2.3
    [DetectorV2.3.csv]
2025-04-12 updated mit logo und neuer schrift
    [DetectorV2.3.kicad_pcb]
2025-04-12 Moved DetectorV2.3 files to hardware folder
    [DetectorV2.3.csv, DetectorV2.3.kicad_pcb, DetectorV2.3.kicad_sch]
2025-04-12 alte versionen
    [DetectorV2.1.kicad_pcb, DetectorV2.2.csv, DetectorV2.2.kicad_pcb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]
2025-04-12 Clean up
    [DetectorV2.1.kicad_pcb, DetectorV2.2.csv, DetectorV2.2.kicad_pcb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]
2025-04-12 updated 2.3 version
    [DetectorV2.3.kicad_pcb]
2025-05-22 oszi test
    [oszi_20250522_200638.csv]
2025-06-06 dioden messung
    [data_freq_100000_settle_10_voltage_16_steps_16_with_black_1Mega_20grad_diode2.csv, data_freq_100000_settle_10_voltage_32_steps_16_with_black_1Mega_20grad_diode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]
